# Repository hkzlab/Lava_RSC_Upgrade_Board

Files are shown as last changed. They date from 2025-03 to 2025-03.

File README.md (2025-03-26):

# Lava RSC Lite Upgrade Board

## DISCLAIMER

Any use of this project is **under your own responsibility**.
You will be responsible of checking the correct construction and functionality of your board.
By using this project You will agree that I cannot be held responsible if it will destroy any of your devices, damage your computer, burn down your house or whatever.

I want to stress this out: You're on your own using this. It works for me, I cannot give guarantees to you. Also, **do not go bother the Lava RSC people about it for support!!!**

## Introduction

The [Lava RSC](http://www.lava-fc.top/) is a family of very nice Famiclones that use ICs found in the original Famicom, complemented with an FPGA used to output an analog RGB picture.

From time to time, the people at Lava update the FPGA firmware to fix bugs and add new features.
The high end model, the Lava RSC, includes an SD card slot connected to an MCU, and is capable of updating the FPGA autonomously, while the Lite version requires an FPGA programmer and 
not-so-easy to obtain Anlogic software to complete the update.

This board reproduces the upgrade circuitry found in a Lava RSC, but as an external module. This way it's sufficient to install headers on your Lite motherboard (there are well marked
spots to solder one), if you want, bring out the signals via a flat cable, and connect this adapter when you want to perform the update. The rest works the same as the original Lava RSC
(beside requiring a Lite-specific firmware, of course).

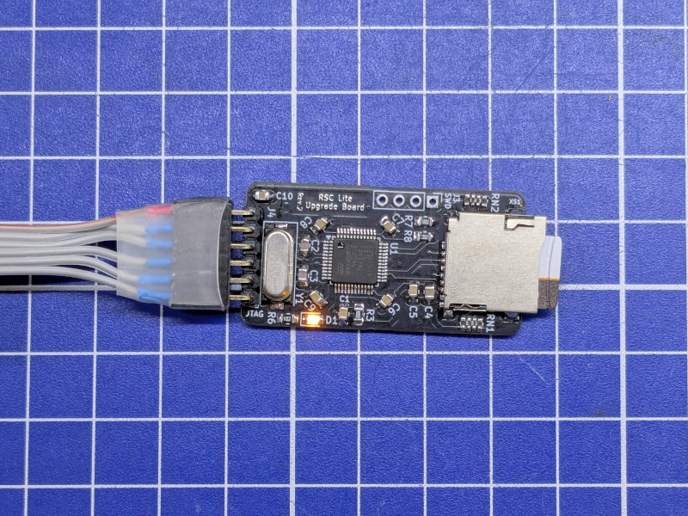
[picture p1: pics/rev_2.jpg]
Closeup of the upgrade board, rev. 2


### Ordering the boards

You can order the board for this project at [PCBWay](https://www.pcbway.com/project/shareproject/Lava_RSC_Lite_Famiclone_Upgrade_board_22eeb25e.html) and support me or download 
the gerbers and have them printed wherever you like!!!

## Hardware

The board was designed with [KiCad](https://kicad.org/) EDA.

### Bill of Materials

This board uses mostly SMD components, but the footprint allows for handsoldering.

| Component | Qty | Type / Value | Notes |
| --- | --- | --- | --- |
| R3, R7, R8 |  1  | 10K 0805 resistor | |
| R6 |  1  | 1K 0805 resistor | |
| RN1, RN2 |  2  | 4-resistor array 4x0612 (1206) | Convex package, the resistors are isolated |
| C2, C3 |  2  | 22pF 10V C0G 0805 capacitors | |
| C1, C5, C6-C9 |  6  | 100nF 10V 0805 capacitors | |
| C4, C10 |  2  | 10uF 10V 0805 capacitors | |
| J3 |  1  | 4pin header, 2.54mm | |
| J4 |  1  | 6pin header, 2.54mm | I prefer using angled ones for this |
| XS1 |  1  | uSD connector | You can find compatible ones on [AliExpress](https://aliexpress.com/item/4000033854553.html) |
| Y1 |  1  | 8Mhz crystal, HC-49SD | |
| U1 |  1  | STM32F103C8T6, LQFP-48 | A compatible GD32F103C8T6 has been tested and found to be working |

### Flashing the STM32

In this repository you'll the firmware file `McuFirmware_dump.hex` dumped from my Lava RSC: it will search for a file named `LavaRSC.aje` in the root
of a FAT32 formatted SD card.

You can use an st-link (a clone is fine) to flash this board via the SWD header (J3). Remember to power the board with **3.3V**.

You can use the `st-flash` utility to program the device:
```
st-flash --format ihex write .\McuFirmware_dump.hex
```

or use the STM32 ST-Link Utility software.

### Using the board to update the Lite

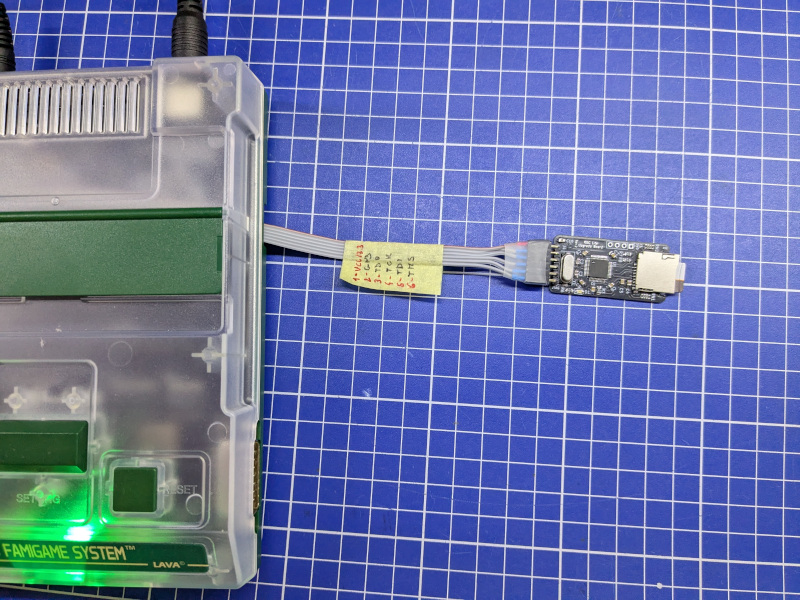
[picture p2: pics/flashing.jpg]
Board connected to a Lite and flashing the firmware


1. Format an SD card to FAT32, make sure it is empty and copy the update files in it (with name `LavaRSC.aje`). You'll find a Lite compatible firmware in this repository, equivalent to the Lava RSC firmware 1.7
2. Plug the SD card in the update board
3. Wire the JTAG connector (J4) to the points of the same name on your Lite motherboard. Dupont wires are ok for this
4. Remove any cart inserted in the Lite
5. If connected, remove any wire connected to the SWD header on the upgrade board
6. Power on the Lite. After a few seconds, the LED on the upgrade board should start flashing
7. Wait until the LED stops flashing and remains on
8. Power off the Lite and remove the upgrade board
9. Done

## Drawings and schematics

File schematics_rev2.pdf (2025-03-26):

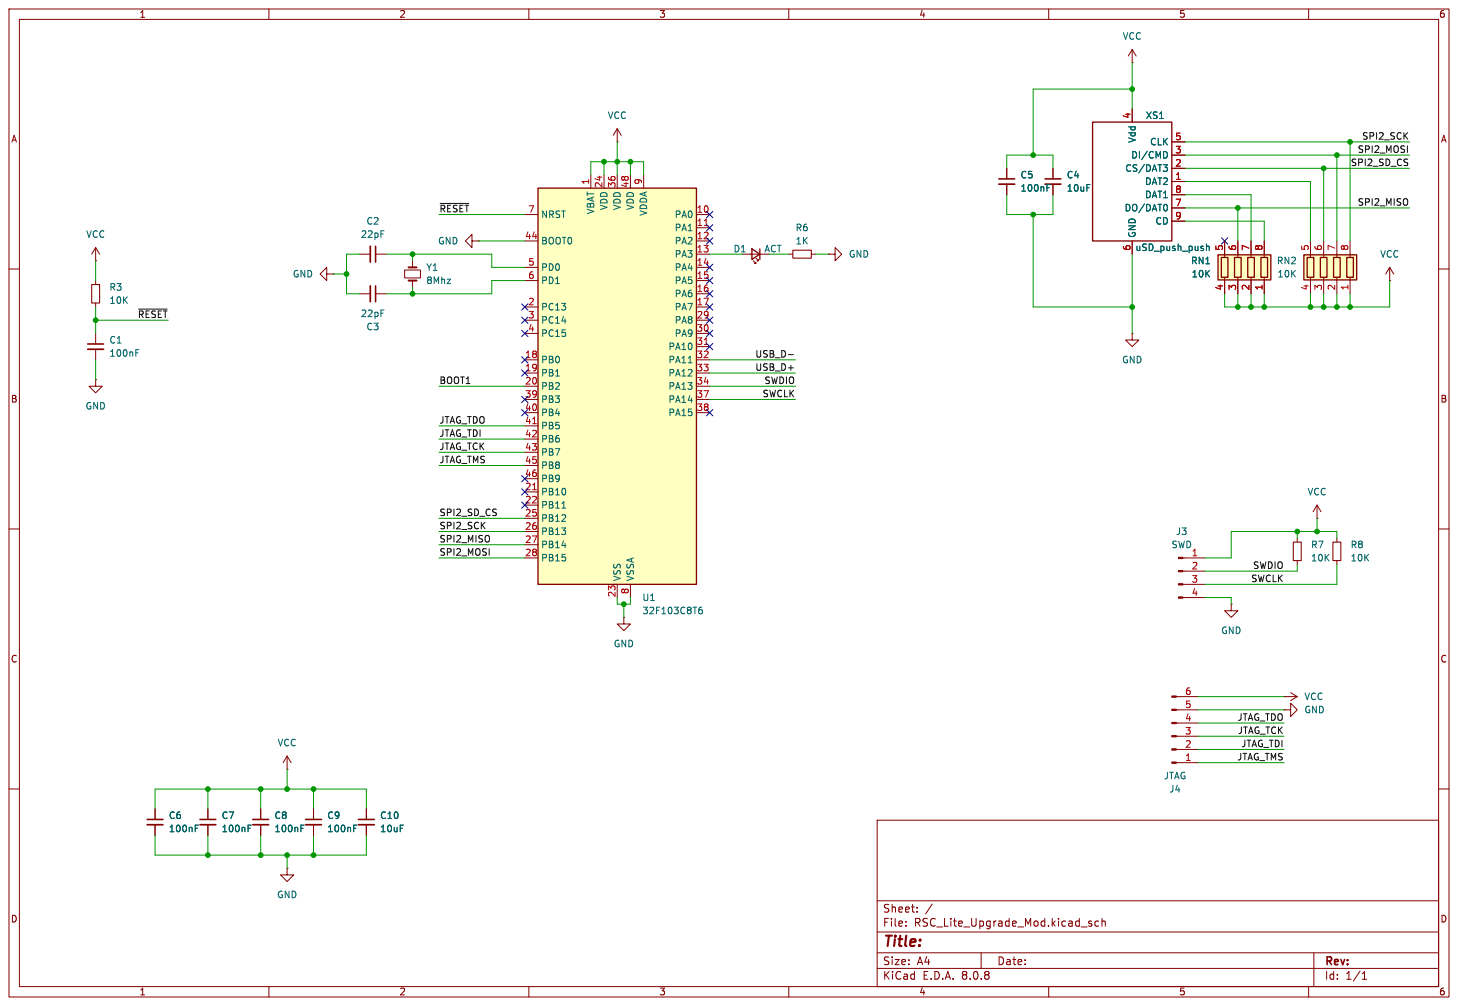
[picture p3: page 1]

1 PA0 10 PA1 11 PA2 12 PA3 13 PA4 14 PA5 15 PA6 16 PA7 17 PB0 18 PB1 19 PC13 2 PB2 20 PB10 21 PB11 22 VSS 23 VDD 24 PB12 25 PB13 26 PB14 27 PB15 28 PA8 29 PC14 3 PA9 30 PA10 31 PA11 32 PA12 33 PA13 34 VDD 36 PA14 37 PA15 38 PB3 39 PC15 4 PB4 40 PB5 41 PB6 42 PB7 43 BOOT0 44 PB8 45 PB9 46 VDD 48 PD0 5 PD1 6 NRST 7 VSSA

VCC GND GND GND

Id: 1/1 Title: File: RSC_Lite_Upgrade_Mod.kicad_sch Sheet: / GND

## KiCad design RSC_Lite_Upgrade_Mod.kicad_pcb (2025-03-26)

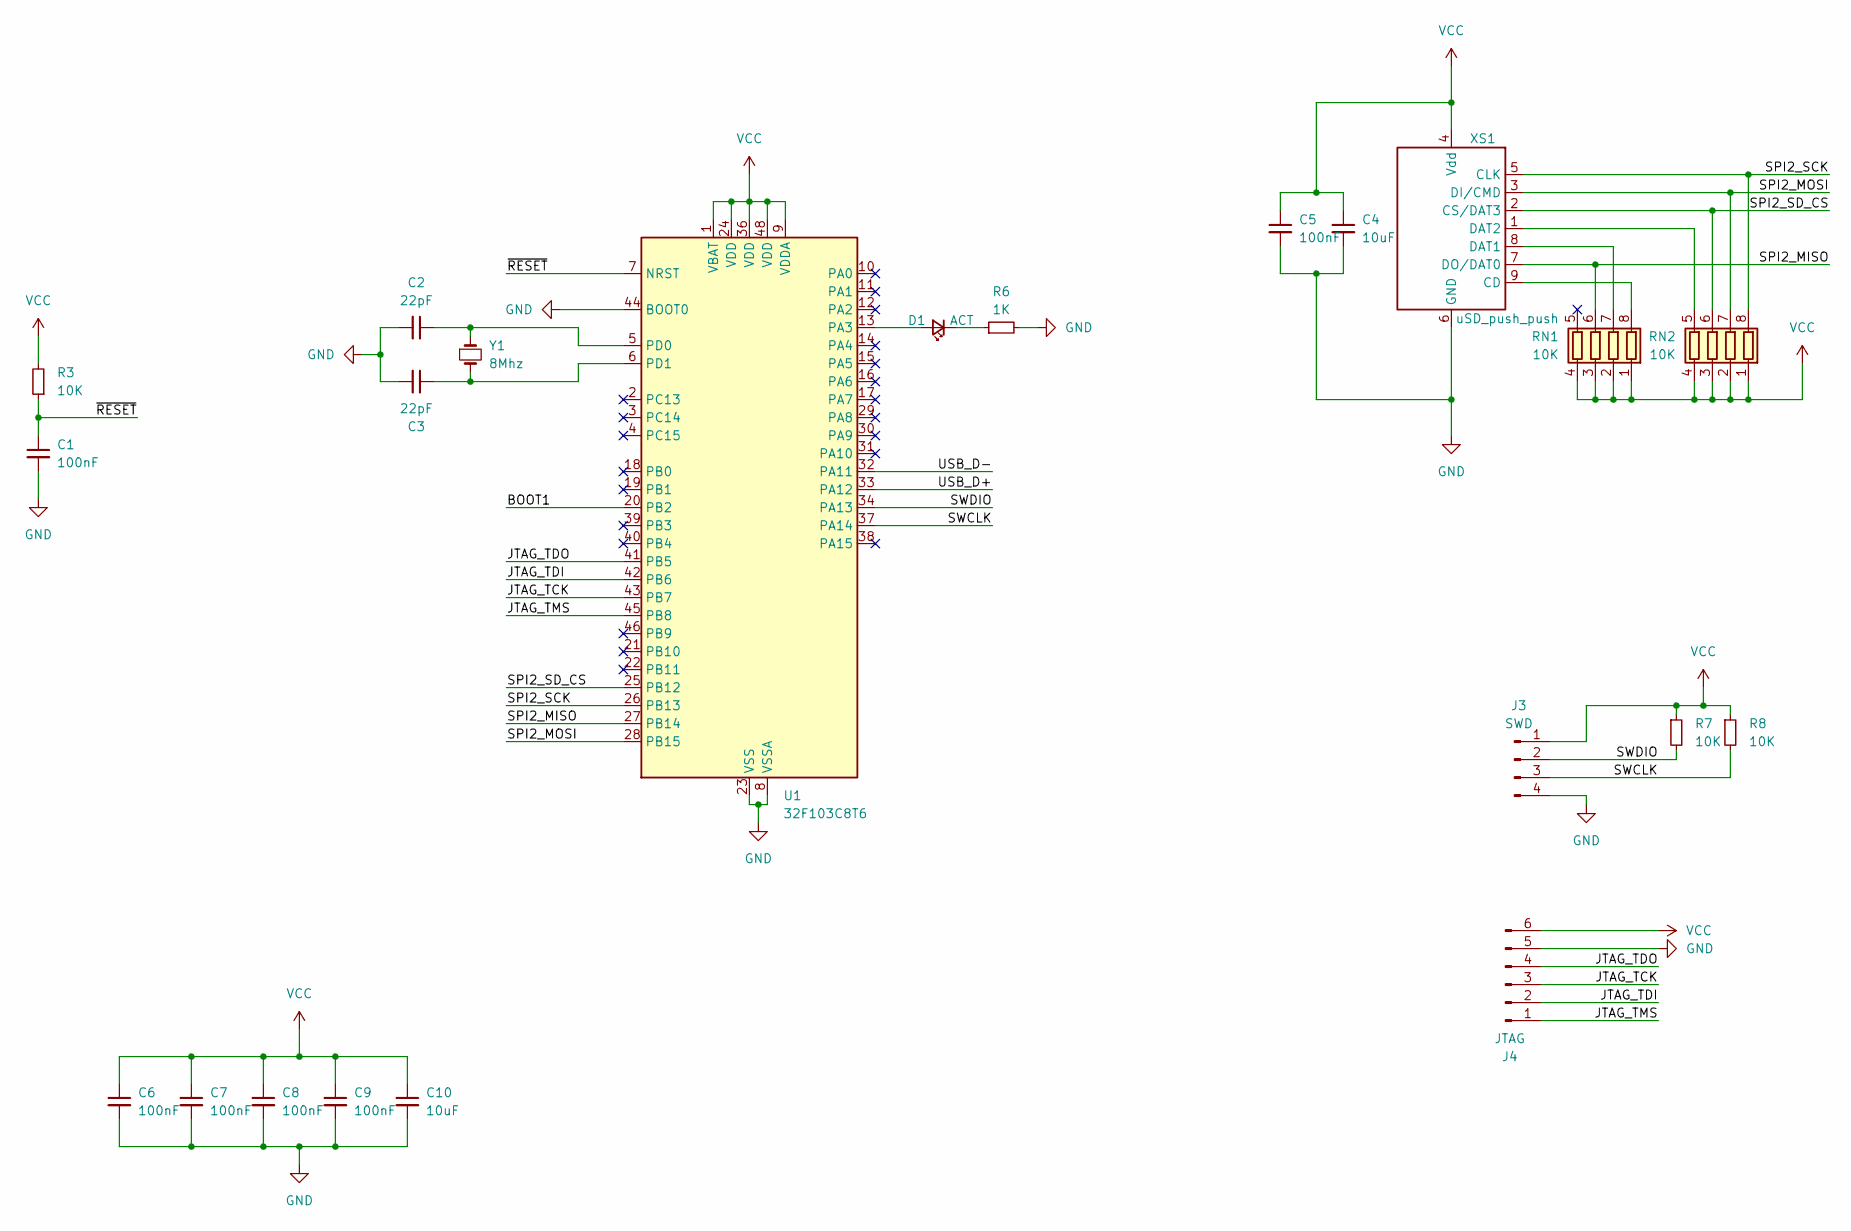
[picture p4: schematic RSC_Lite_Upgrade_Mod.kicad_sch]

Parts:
C1, C5, C6, C7, C8, C9: 100nF; C_0805_2012Metric_Pad1.18x1.45mm_HandSolder
C2, C3: 22pF; C_0805_2012Metric_Pad1.18x1.45mm_HandSolder
C4, C10: 10uF; C_0805_2012Metric_Pad1.18x1.45mm_HandSolder
D1: ACT; LED_0805_2012Metric_Pad1.15x1.40mm_HandSolder
J3: SWD; PinHeader_1x04_P2.54mm_Vertical
J4: JTAG; PinHeader_1x06_P2.54mm_Horizontal
R3, R7, R8: 10K; R_0805_2012Metric_Pad1.20x1.40mm_HandSolder
R6: 1K; R_0805_2012Metric_Pad1.20x1.40mm_HandSolder
RN1, RN2: 10K; R_Array_Convex_4x0612
U1: 32F103C8T6; LQFP-48_7x7mm_P0.5mm
XS1: uSD_push_push; Conn_uSDcard
Y1: 8Mhz; Crystal_SMD_HC49-SD

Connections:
/BOOT1: U1.20 (PB2)
/JTAG_TCK: J4.3, U1.43 (PB7)
/JTAG_TDI: J4.2, U1.42 (PB6)
/JTAG_TDO: J4.4, U1.41 (PB5)
/JTAG_TMS: J4.1, U1.45 (PB8)
/SPI2_MISO: RN1.6 (R3.2), U1.27 (PB14), XS1.7 (DO/DAT0)
/SPI2_MOSI: RN2.7 (R2.2), U1.28 (PB15), XS1.3 (DI/CMD)
/SPI2_SCK: RN2.8 (R1.2), U1.26 (PB13), XS1.5 (CLK)
/SPI2_SD_CS: RN2.6 (R3.2), U1.25 (PB12), XS1.2 (CS/DAT3)
/SWCLK: J3.3, R8.2, U1.37 (PA14)
/SWDIO: J3.2, R7.2, U1.34 (PA13)
/USB_D+: U1.33 (PA12)
/USB_D-: U1.32 (PA11)
/~RESET: C1.1, R3.1, U1.7 (NRST)
GND: C1.2, C2.2, C3.2, C4.2, C5.2, C6.2, C7.2, C8.2, C9.2, C10.2, J3.4, J4.5, R6.2, U1.8 (VSSA), U1.23 (VSS), U1.35 (VSS), U1.44 (BOOT0), U1.47 (VSS), XS1.6 (GND)
unnamed: D1.2 (A), U1.13 (PA3)
unnamed: D1.1 (K), R6.1
unnamed: RN1.8 (R1.2), XS1.9 (CD)
unnamed: RN1.7 (R2.2), XS1.8 (DAT1)
unnamed: RN2.5 (R4.2), XS1.1 (DAT2)
unnamed: C2.1, U1.5 (PD0), Y1.1
unnamed: C3.1, U1.6 (PD1), Y1.2
VCC: C4.1, C5.1, C6.1, C7.1, C8.1, C9.1, C10.1, J3.1, J4.6, R3.2, R7.1, R8.1, RN1.1 (R1.1), RN1.2 (R2.1), RN1.3 (R3.1), RN1.4 (R4.1), RN2.1 (R1.1), RN2.2 (R2.1), RN2.3 (R3.1), RN2.4 (R4.1), U1.1 (VBAT), U1.9 (VDDA), U1.24 (VDD), U1.36 (VDD), U1.48 (VDD), XS1.4 (Vdd)

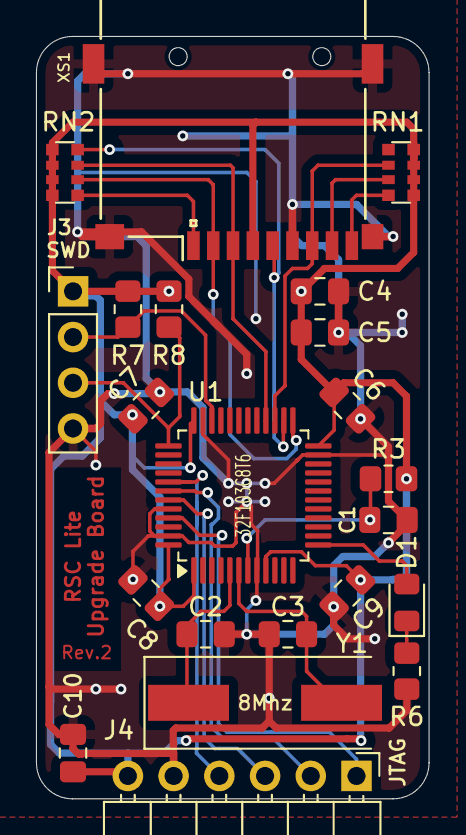
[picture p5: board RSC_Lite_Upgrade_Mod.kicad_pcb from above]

Board: 2 copper layers, 21.8 x 42.4 mm, 22 parts (0 on the bottom side), 20 nets.

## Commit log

2025-01-03 :c :x
    [RSC_Lite_Upgrade_Mod.kicad_pcb, RSC_Lite_Upgrade_Mod.kicad_sch]
2025-01-03 Begin drawing the RSC Lite upgrade mod circuit
    [RSC_Lite_Upgrade_Mod.kicad_sch]
2025-01-03 Update schematics
    [RSC_Lite_Upgrade_Mod.kicad_sch]
2025-01-04 Basic routing for the board
    [RSC_Lite_Upgrade_Mod.kicad_pcb, RSC_Lite_Upgrade_Mod.kicad_sch]
2025-01-04 Update pcb
    [RSC_Lite_Upgrade_Mod.kicad_pcb]
2025-01-04 Update the PCB
    [RSC_Lite_Upgrade_Mod.kicad_pcb]
2025-01-04 add another gnd via
    [RSC_Lite_Upgrade_Mod.kicad_pcb]
2025-01-04 move some silkscreen
    [RSC_Lite_Upgrade_Mod.kicad_pcb]
2025-01-04 Reorganize some traces
    [RSC_Lite_Upgrade_Mod.kicad_pcb]
2025-01-06 Update PCB layout
    [RSC_Lite_Upgrade_Mod.kicad_pcb]
2025-01-06 Move some traces around
    [RSC_Lite_Upgrade_Mod.kicad_pcb]
2025-01-06 Update board and generate gerbers
    [RSC_Lite_Upgrade_Mod.kicad_pcb]
2025-02-15 Add gerbers and firmware for revision 1
    [RSC_Lite_Upgrade_Mod.kicad_pcb, RSC_Lite_Upgrade_Mod.kicad_sch]
2025-02-15 Add rev.1 schematics
2025-02-15 Add PCBWay project link
